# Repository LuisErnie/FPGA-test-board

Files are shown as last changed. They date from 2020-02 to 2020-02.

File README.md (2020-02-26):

# FPGA-test-board
FPGA Test Board designed for use with **DE10-NANO** by Terasic to provide external I/O devices to interface with the FPGA:
- 40 pin GPIO header split into 5 PMod ports
- 16x2 Character LCD
- 2 UART RS-485 ports
- 1 UART RS-282/USB port selected with switch
- 8 Optocoupled Outputs
- 8 ADC inputs 12-bit
- 8 DIP switch input

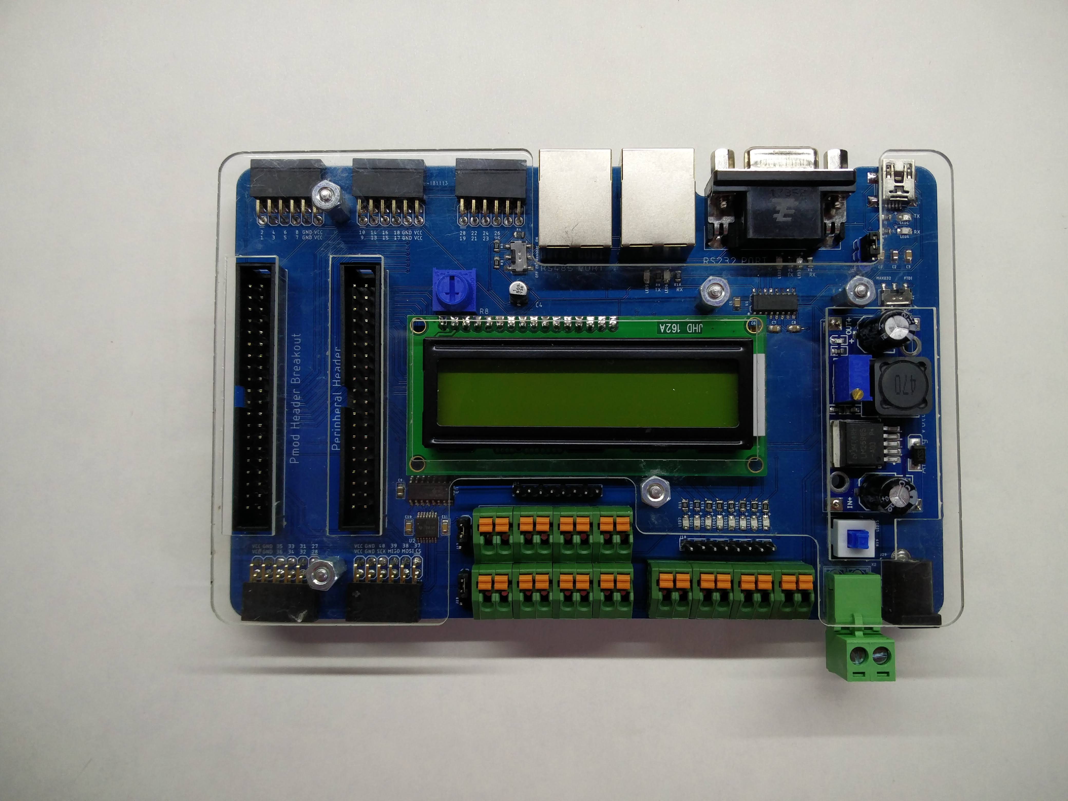
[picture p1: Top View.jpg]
Board


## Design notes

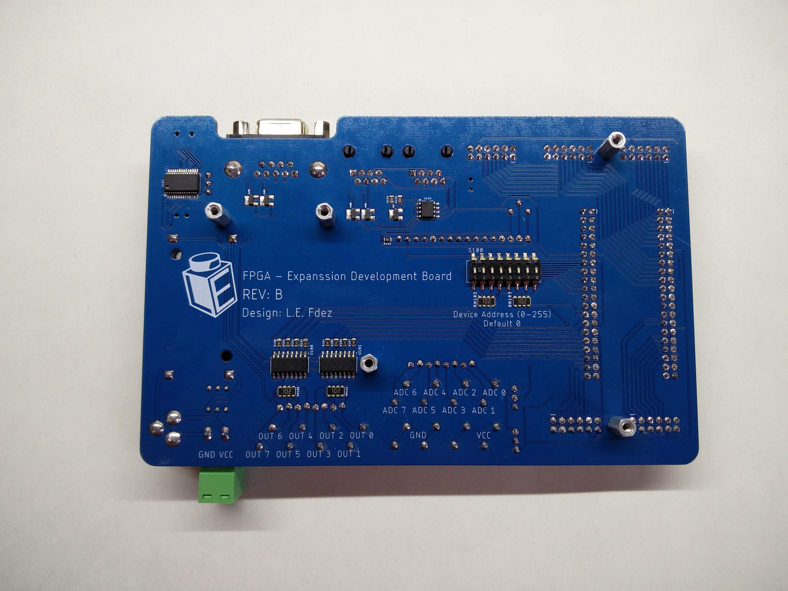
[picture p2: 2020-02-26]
Bottom View.jpg

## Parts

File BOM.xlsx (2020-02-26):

LCSC Part Number | Manufacture Part Number | Manufacturer | Package | RoHS | Order Qty. | Unit Price | Min\Mult Order Qty. | Order Price
C18148 | MAX3485ESA+T | Maxim Integrated | SOIC-8_150mil | yes | 5 | 1.632 | 1 | 8.16
C7258 | MAX3232CSE+T | Maxim Integrated | SOIC-16_150mil | yes | 5 | 1.1077 | 1 | 5.5385
C167327 | 3-1634584-2 | TE Connectivity | Connector | - | 5 | 1.3428 | 1 | 6.714
C116302 | 3386P-1-103TLF | BOURNS | 3386P | yes | 5 | 1.2498 | 1 | 6.249
C107402 | D-G080508G1-KS2 | Wuxi ARK Tech Elec | 0805 | - | 60 | 0.0203 | 20 | 1.218
C108412 | D-B080508B1-KS2 | Wuxi ARK Tech Elec | 0805 | - | 60 | 0.022 | 20 | 1.32
C91144 | U-M-M5SS-W-2 | Rectangular Connectors - Contacts | SMD | - | 5 | 0.115 | 5 | 0.575
C16338 | 2N7002LT1G | ON Semicon | SOT-23(SOT-23-3) | yes | 30 | 0.0592 | 10 | 1.776
C29926 | 0805B104J500NT | Guangdong Fenghua Advanced Tech | 0805 | yes | 20 | 0.0258 | 20 | 0.516
C60708 | TXB0104PWR | Texas Instruments | TSSOP-14 | yes | 5 | 0.7644 | 1 | 3.822
C144126 | AF0805JR-07100RL | YAGEO | 0805 | yes | 100 | 0.0104 | 50 | 1.04
C100046 | RC0805JR-071KL | YAGEO | 0805 | - | 50 | 0.0027 | 50 | 0.135
C138260 | AC0805JR-0710KL | YAGEO | 0805 | yes | 50 | 0.0131 | 50 | 0.655
C39060 | 0805F106M250NT | Guangdong Fenghua Advanced Tech | 0805 | yes | 10 | 0.0609 | 10 | 0.609
C35795 | 0805F105M500NT | Guangdong Fenghua Advanced Tech | 0805 | yes | 20 | 0.0254 | 20 | 0.508
C37818 | 0805B475K250NT | Guangdong Fenghua Advanced Tech | 0805 | yes | 10 | 0.0657 | 10 | 0.657
C178506 | EEE1HA010SR | PANASONIC | SMD,4x5.4mm | yes | 5 | 0.0639 | 5 | 0.3195
C229170 | AC0805JR-07270RL | YAGEO | 0805 | yes | 50 | 0.0047 | 50 | 0.235
C8690 | FT232RL-REEL | Future Designs | SSOP-28_208mil | yes | 5 | 3.5565 | 1 | 17.7825
C89710 | EMR-08-V | Diptronics | SMD | - | 5 | 0.4701 | 1 | 2.3505
C239357 | A2541HWR-2x6P | Changjiang Connectors | Through Hole,P=2.54mm | yes | 30 | 0.2114 | 1 | 6.342
C173392 | 41-F01-250-4 | HIWA | P=3.5mm | - | 20 | 0.1471 | 1 | 2.942
C183518 | 5EHDR-02P | Dinkle | Through Hole,P=5mm | - | 5 | 0.1387 | 1 | 0.6935
C183512 | 5ESDV-02P | Dinkle | Plug,P=5mm | - | 5 | 0.296 | 1 | 1.48
C136744 | DC-005-20A | Rectangular Connectors - Contacts | 14.0*9.0mm | yes | 5 | 0.0947 | 5 | 0.4735
C124009 | K8-8081D-L1 | Rectangular Connectors - Contacts | Self-locking Button Switch | - | 5 | 0.1184 | 1 | 0.592
C118300 | TCMT4600 | Vishay Intertech | SO-16 | yes | 10 | 1.0299 | 1 | 10.299
C132439 | - | Shenzhen Cankemeng | DIP P=2.54mm | yes | 10 | 0.2029 | 1 | 2.029
C149873 | CRA064RJ1KE04 | Ever Ohms Tech | 1206_x4 | yes | 20 | 0.0602 | 10 | 1.204
C86576 | DS1128-04-S8B8P-X | CONNFLY Elec | Plugin | yes | 10 | 0.3907 | 1 | 3.907

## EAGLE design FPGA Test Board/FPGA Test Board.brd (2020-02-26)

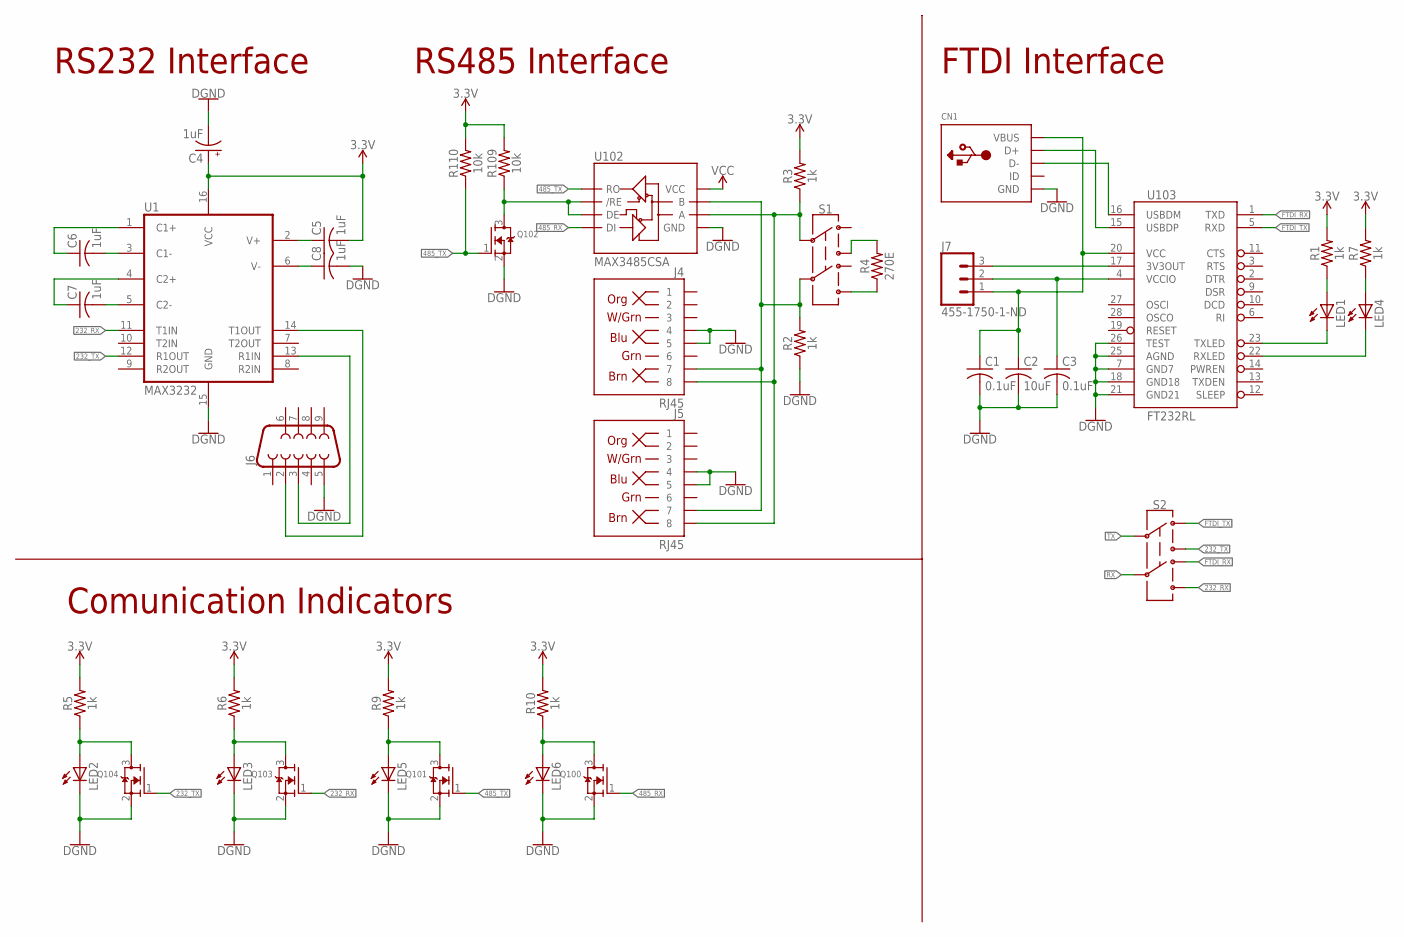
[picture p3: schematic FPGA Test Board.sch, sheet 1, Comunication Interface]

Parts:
C1, C3: 0.1uF; C0805
C2: 10uF; C0805
C4: 1uF; PANASONIC_B
C5, C6, C7, C8: 1uF; C0805
CN1: USBMINIB; USB-MINIB
J4, J5: RJ45; RJ45-8
J6: DB9FEMALE; DB9
J7: 455-1750-1-ND; 1X03
LED1, LED2, LED3, LED4, LED5, LED6: LEDCHIP-LED0805; CHIP-LED0805
Q100, Q101, Q102, Q103, Q104: MOSFET-NWAVE; SOT23-W
R1, R2, R3, R5, R6, R7, R9, R10: 1k; 0805
R4: 270E; 0805
R109, R110: 10k; 0805
S1, S2: SWITCH-DPDT-SMD-AYZ0202; SWITCH_DPDT_SMD_AYZ0202
U1: MAX3232; SO16
U102: MAX3485CSA; SO08
U103: FT232RL; SSOP28DB

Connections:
3.3V: C4.+, C5.2, R1.2, R3.2, R5.2, R6.2, R7.2, R9.2, R10.2, R109.2, R110.2, U1.16 (VCC); also elsewhere on the board
5V: U102.8 (VCC); also elsewhere on the board
232_RX: Q103.1 (G), S2.6, U1.11 (T1IN); also elsewhere on the board
232_TX: Q104.1 (G), S2.3, U1.12 (R1OUT); also elsewhere on the board
485_RX: Q100.1 (G), U102.4 (DI); also elsewhere on the board
485_TX: Q101.1 (G), Q102.1 (G), R110.1, U102.1 (RO); also elsewhere on the board
FTDI_RX: S2.4, U103.1 (TXD)
FTDI_TX: S2.1, U103.5 (RXD)
GND: C1.2, C2.2, C3.2, C4.-, C8.2, CN1.GND, J4.4, J4.5, J5.4, J5.5, J6.5, LED2.C, LED3.C, LED5.C, LED6.C, Q100.2 (S), Q101.2 (S), Q102.2 (S), Q103.2 (S), Q104.2 (S), R2.1, U1.15 (GND), U102.5 (GND), U103.7 (GND7), U103.18 (GND18), U103.21 (GND21), U103.25 (AGND), U103.26 (TEST); also elsewhere on the board
unnamed: C6.2, U1.3 (C1-)
unnamed: C5.1, U1.2 (V+)
unnamed: C6.1, U1.1 (C1+)
unnamed: C7.1, U1.4 (C2+)
unnamed: C7.2, U1.5 (C2-)
unnamed: C8.1, U1.6 (V-)
unnamed: J4.8, J5.8, R3.1, S1.2, U102.6 (A)
unnamed: LED3.A, Q103.3 (D), R6.1
unnamed: J6.2, U1.14 (T1OUT)
unnamed: J6.3, U1.13 (R1IN)
unnamed: LED5.A, Q101.3 (D), R9.1
unnamed: LED2.A, Q104.3 (D), R5.1
unnamed: LED6.A, Q100.3 (D), R10.1
unnamed: J4.7, J5.7, R2.2, S1.5, U102.7 (B)
unnamed: R4.1, S1.6
unnamed: Q102.3 (D), R109.1, U102.2 (/RE), U102.3 (DE)
unnamed: R4.2, S1.3
unnamed: C1.1, C2.1, CN1.VBUS, J7.1, U103.20 (VCC)
unnamed: LED1.A, R1.1
unnamed: LED1.C, U103.23 (TXLED)
unnamed: LED4.A, R7.1
unnamed: LED4.C, U103.22 (RXLED)
unnamed: CN1.D-, U103.16 (USBDM)
unnamed: CN1.D+, U103.15 (USBDP)
unnamed: J7.3, U103.17 (3V3OUT)
unnamed: C3.1, J7.2, U103.4 (VCCIO)
RX: S2.5
TX: S2.2

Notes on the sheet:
RS232 Interface
RS485 Interface
Comunication Indicators
FTDI Interface

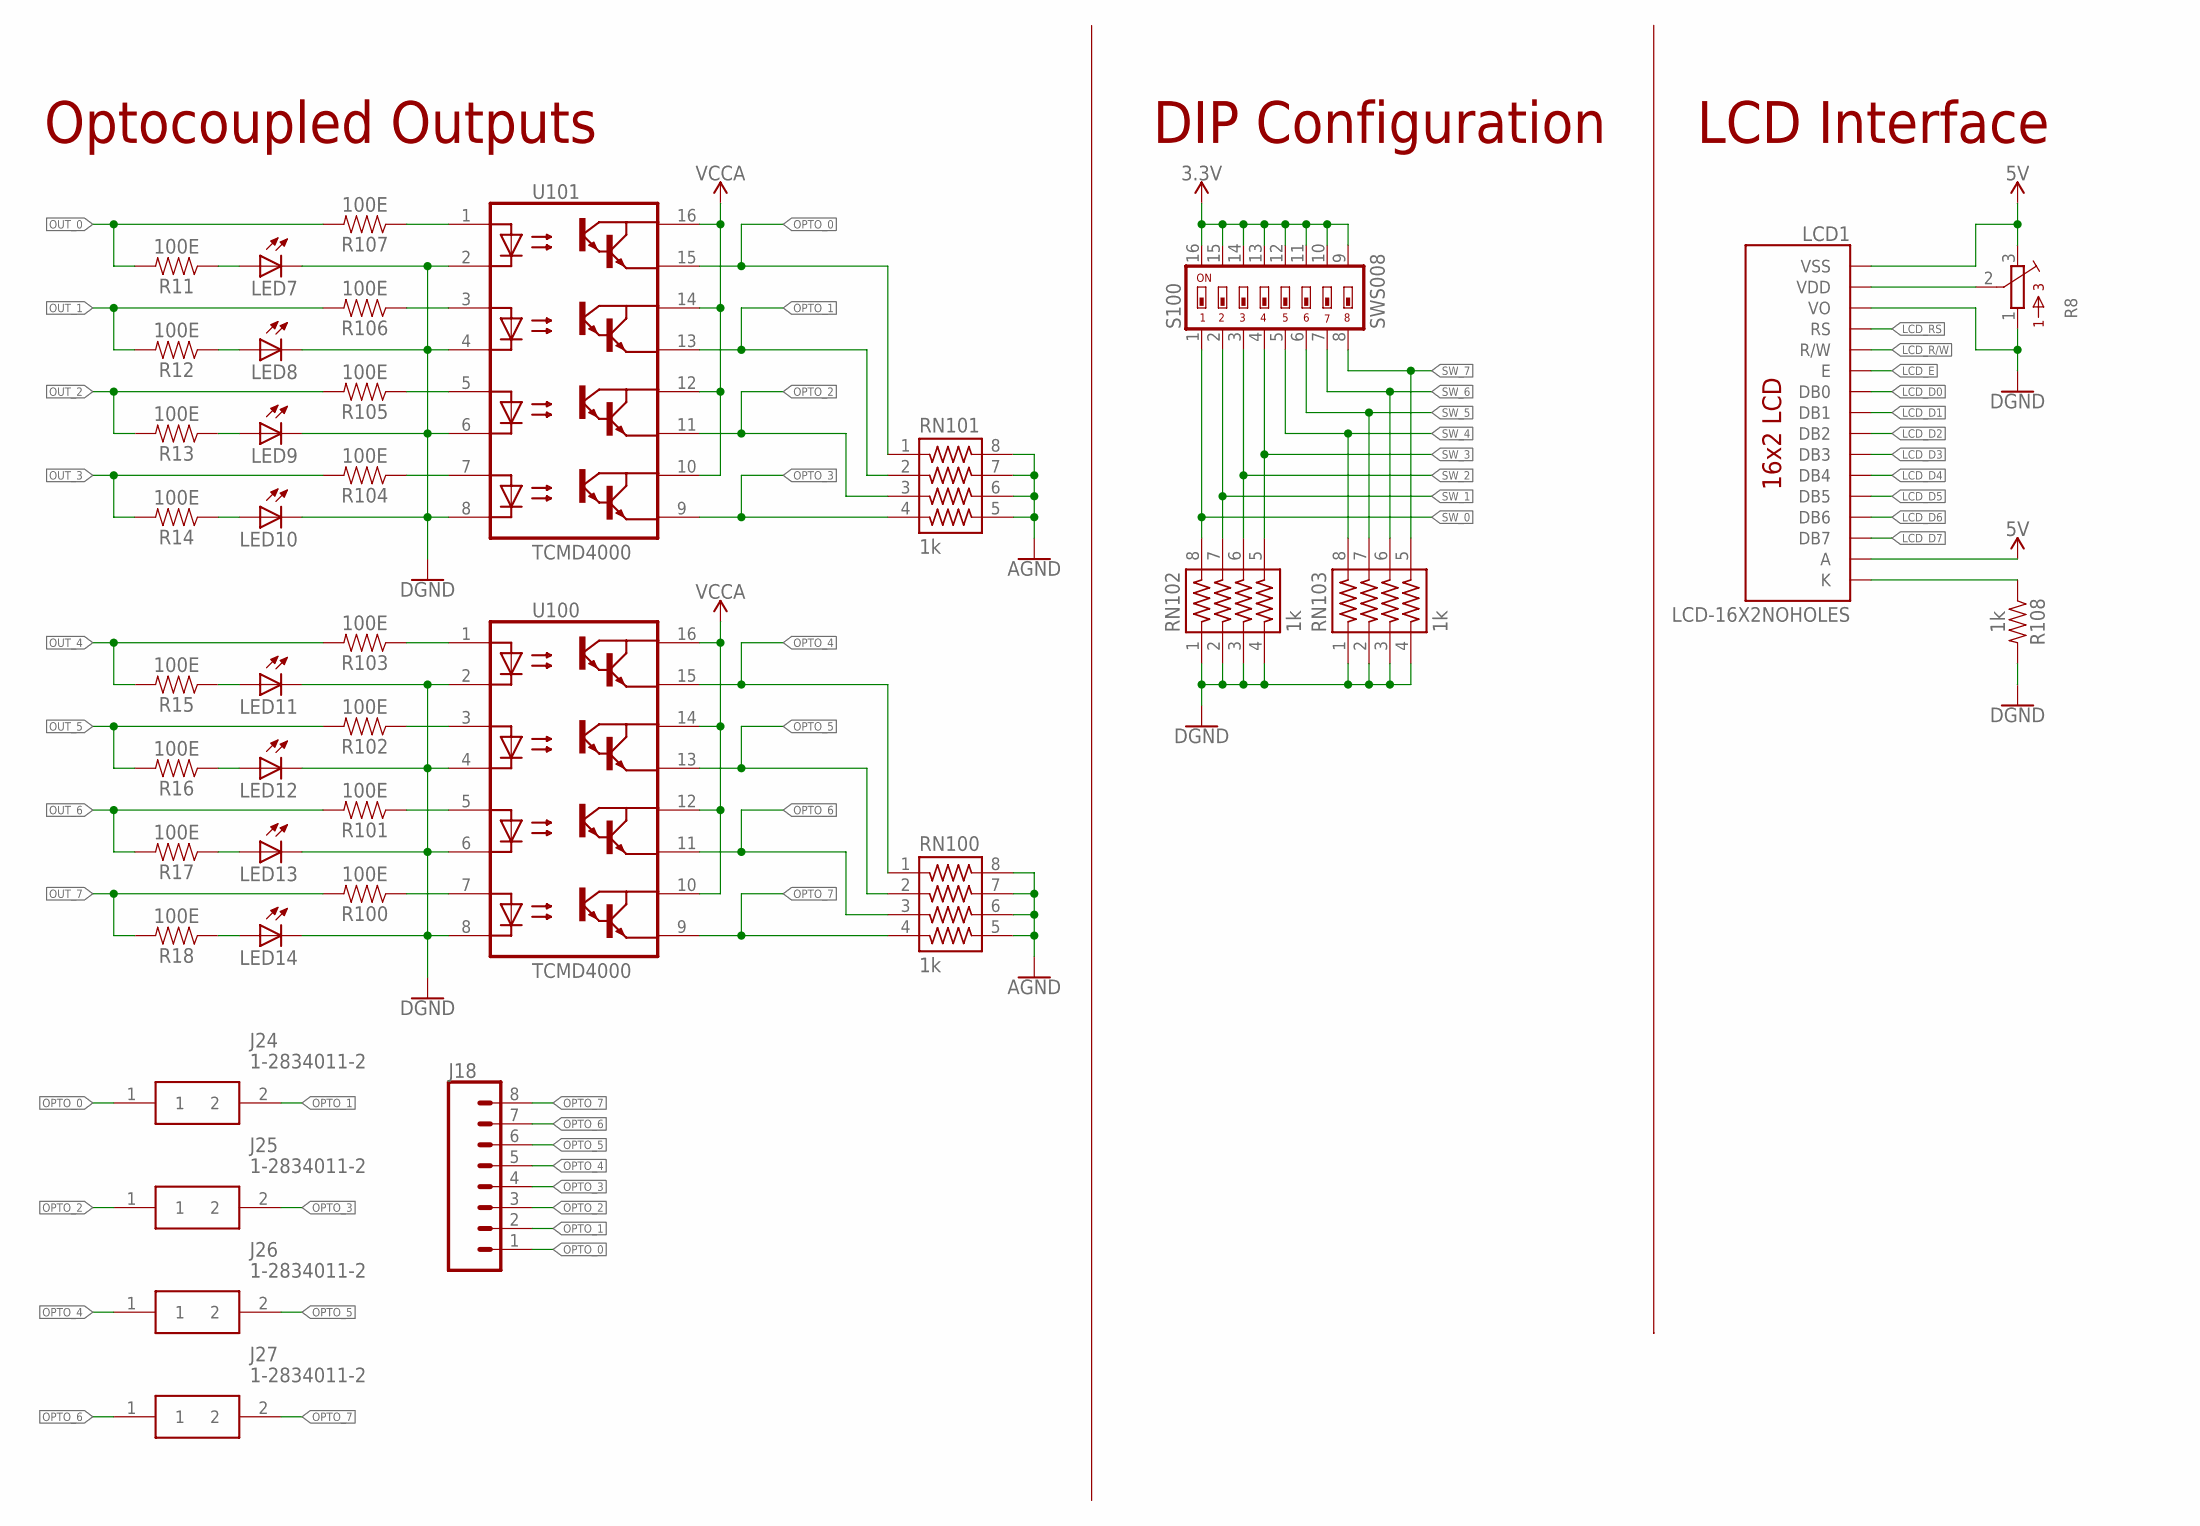
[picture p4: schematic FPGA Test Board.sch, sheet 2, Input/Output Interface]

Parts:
J18: CONN_08FEMALE_LOCK; 1X08_FEMALE_LOCK
J24, J25, J26, J27: 1-2834011-2; 128340112
LCD1: LCD-16X2NOHOLES; LCD-16X2_NOHOLESNOSILK
LED7, LED8, LED9, LED10, LED11, LED12, LED13, LED14: LEDCHIP-LED0805; CHIP-LED0805
R8: 3386-P; 3386P
R11, R12, R13, R14, R15, R16, R17, R18, R100, R101, R102, R103, R104, R105, R106, R107: 100E; 0805
R108: 1k; 0805
RN100, RN101, RN102, RN103: 1k; 743-8NS
S100: SWS008; SMS-008
U100, U101: TCMD4000; SOIC127P686X201-16N

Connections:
3.3V: S100.9, S100.10, S100.11, S100.12, S100.13, S100.14, S100.15, S100.16; also elsewhere on the board
5V: LCD1.1 (VSS), LCD1.15 (A), R8.3; also elsewhere on the board
AGND: RN100.5, RN100.6, RN100.7, RN100.8, RN101.5, RN101.6, RN101.7, RN101.8; also elsewhere on the board
GND: LCD1.3 (VO), LED7.C, LED8.C, LED9.C, LED10.C, LED11.C, LED12.C, LED13.C, LED14.C, R8.1, R108.2, RN102.1, RN102.2, RN102.3, RN102.4, RN103.1, RN103.2, RN103.3, RN103.4, U100.2 (C1), U100.4 (C2), U100.6 (C3), U100.8 (C4), U101.2 (C1), U101.4 (C2), U101.6 (C3), U101.8 (C4); also elsewhere on the board
LCD_D0: LCD1.7 (DB0); also elsewhere on the board
LCD_D1: LCD1.8 (DB1); also elsewhere on the board
LCD_D2: LCD1.9 (DB2); also elsewhere on the board
LCD_D3: LCD1.10 (DB3); also elsewhere on the board
LCD_D4: LCD1.11 (DB4); also elsewhere on the board
LCD_D5: LCD1.12 (DB5); also elsewhere on the board
LCD_D6: LCD1.13 (DB6); also elsewhere on the board
LCD_D7: LCD1.14 (DB7); also elsewhere on the board
LCD_E: LCD1.6 (E); also elsewhere on the board
LCD_R/W: LCD1.5 (R/W); also elsewhere on the board
LCD_RS: LCD1.4 (RS); also elsewhere on the board
unnamed: LCD1.2 (VDD), R8.2
unnamed: LCD1.16 (K), R108.1
unnamed: R107.1, U101.1 (A1)
unnamed: R106.1, U101.3 (A2)
unnamed: R105.1, U101.5 (A3)
unnamed: R104.1, U101.7 (A4)
unnamed: LED10.A, R14.1
unnamed: LED9.A, R13.1
unnamed: LED8.A, R12.1
unnamed: LED7.A, R11.1
unnamed: R103.1, U100.1 (A1)
unnamed: R102.1, U100.3 (A2)
unnamed: R101.1, U100.5 (A3)
unnamed: R100.1, U100.7 (A4)
unnamed: LED14.A, R18.1
unnamed: LED13.A, R17.1
unnamed: LED12.A, R16.1
unnamed: LED11.A, R15.1
OPTO_0: J18.1, J24.1, RN101.1, U101.15 (E1)
OPTO_1: J18.2, J24.2, RN101.2, U101.13 (E2)
OPTO_2: J18.3, J25.1, RN101.3, U101.11 (E3)
OPTO_3: J18.4, J25.2, RN101.4, U101.9 (E4)
OPTO_4: J18.5, J26.1, RN100.1, U100.15 (E1)
OPTO_5: J18.6, J26.2, RN100.2, U100.13 (E2)
OPTO_6: J18.7, J27.1, RN100.3, U100.11 (E3)
OPTO_7: J18.8, J27.2, RN100.4, U100.9 (E4)
OUT_0: R11.2, R107.2; also elsewhere on the board
OUT_1: R12.2, R106.2; also elsewhere on the board
OUT_2: R13.2, R105.2; also elsewhere on the board
OUT_3: R14.2, R104.2; also elsewhere on the board
OUT_4: R15.2, R103.2; also elsewhere on the board
OUT_5: R16.2, R102.2; also elsewhere on the board
OUT_6: R17.2, R101.2; also elsewhere on the board
OUT_7: R18.2, R100.2; also elsewhere on the board
SW_0: RN102.8, S100.1; also elsewhere on the board
SW_1: RN102.7, S100.2; also elsewhere on the board
SW_2: RN102.6, S100.3; also elsewhere on the board
SW_3: RN102.5, S100.4; also elsewhere on the board
SW_4: RN103.8, S100.5; also elsewhere on the board
SW_5: RN103.7, S100.6; also elsewhere on the board
SW_6: RN103.6, S100.7; also elsewhere on the board
SW_7: RN103.5, S100.8; also elsewhere on the board
VCCA: U100.10 (CO4), U100.12 (CO3), U100.14 (CO2), U100.16 (CO1), U101.10 (CO4), U101.12 (CO3), U101.14 (CO2), U101.16 (CO1); also elsewhere on the board

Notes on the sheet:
Optocoupled Outputs
DIP Configuration
LCD Interface

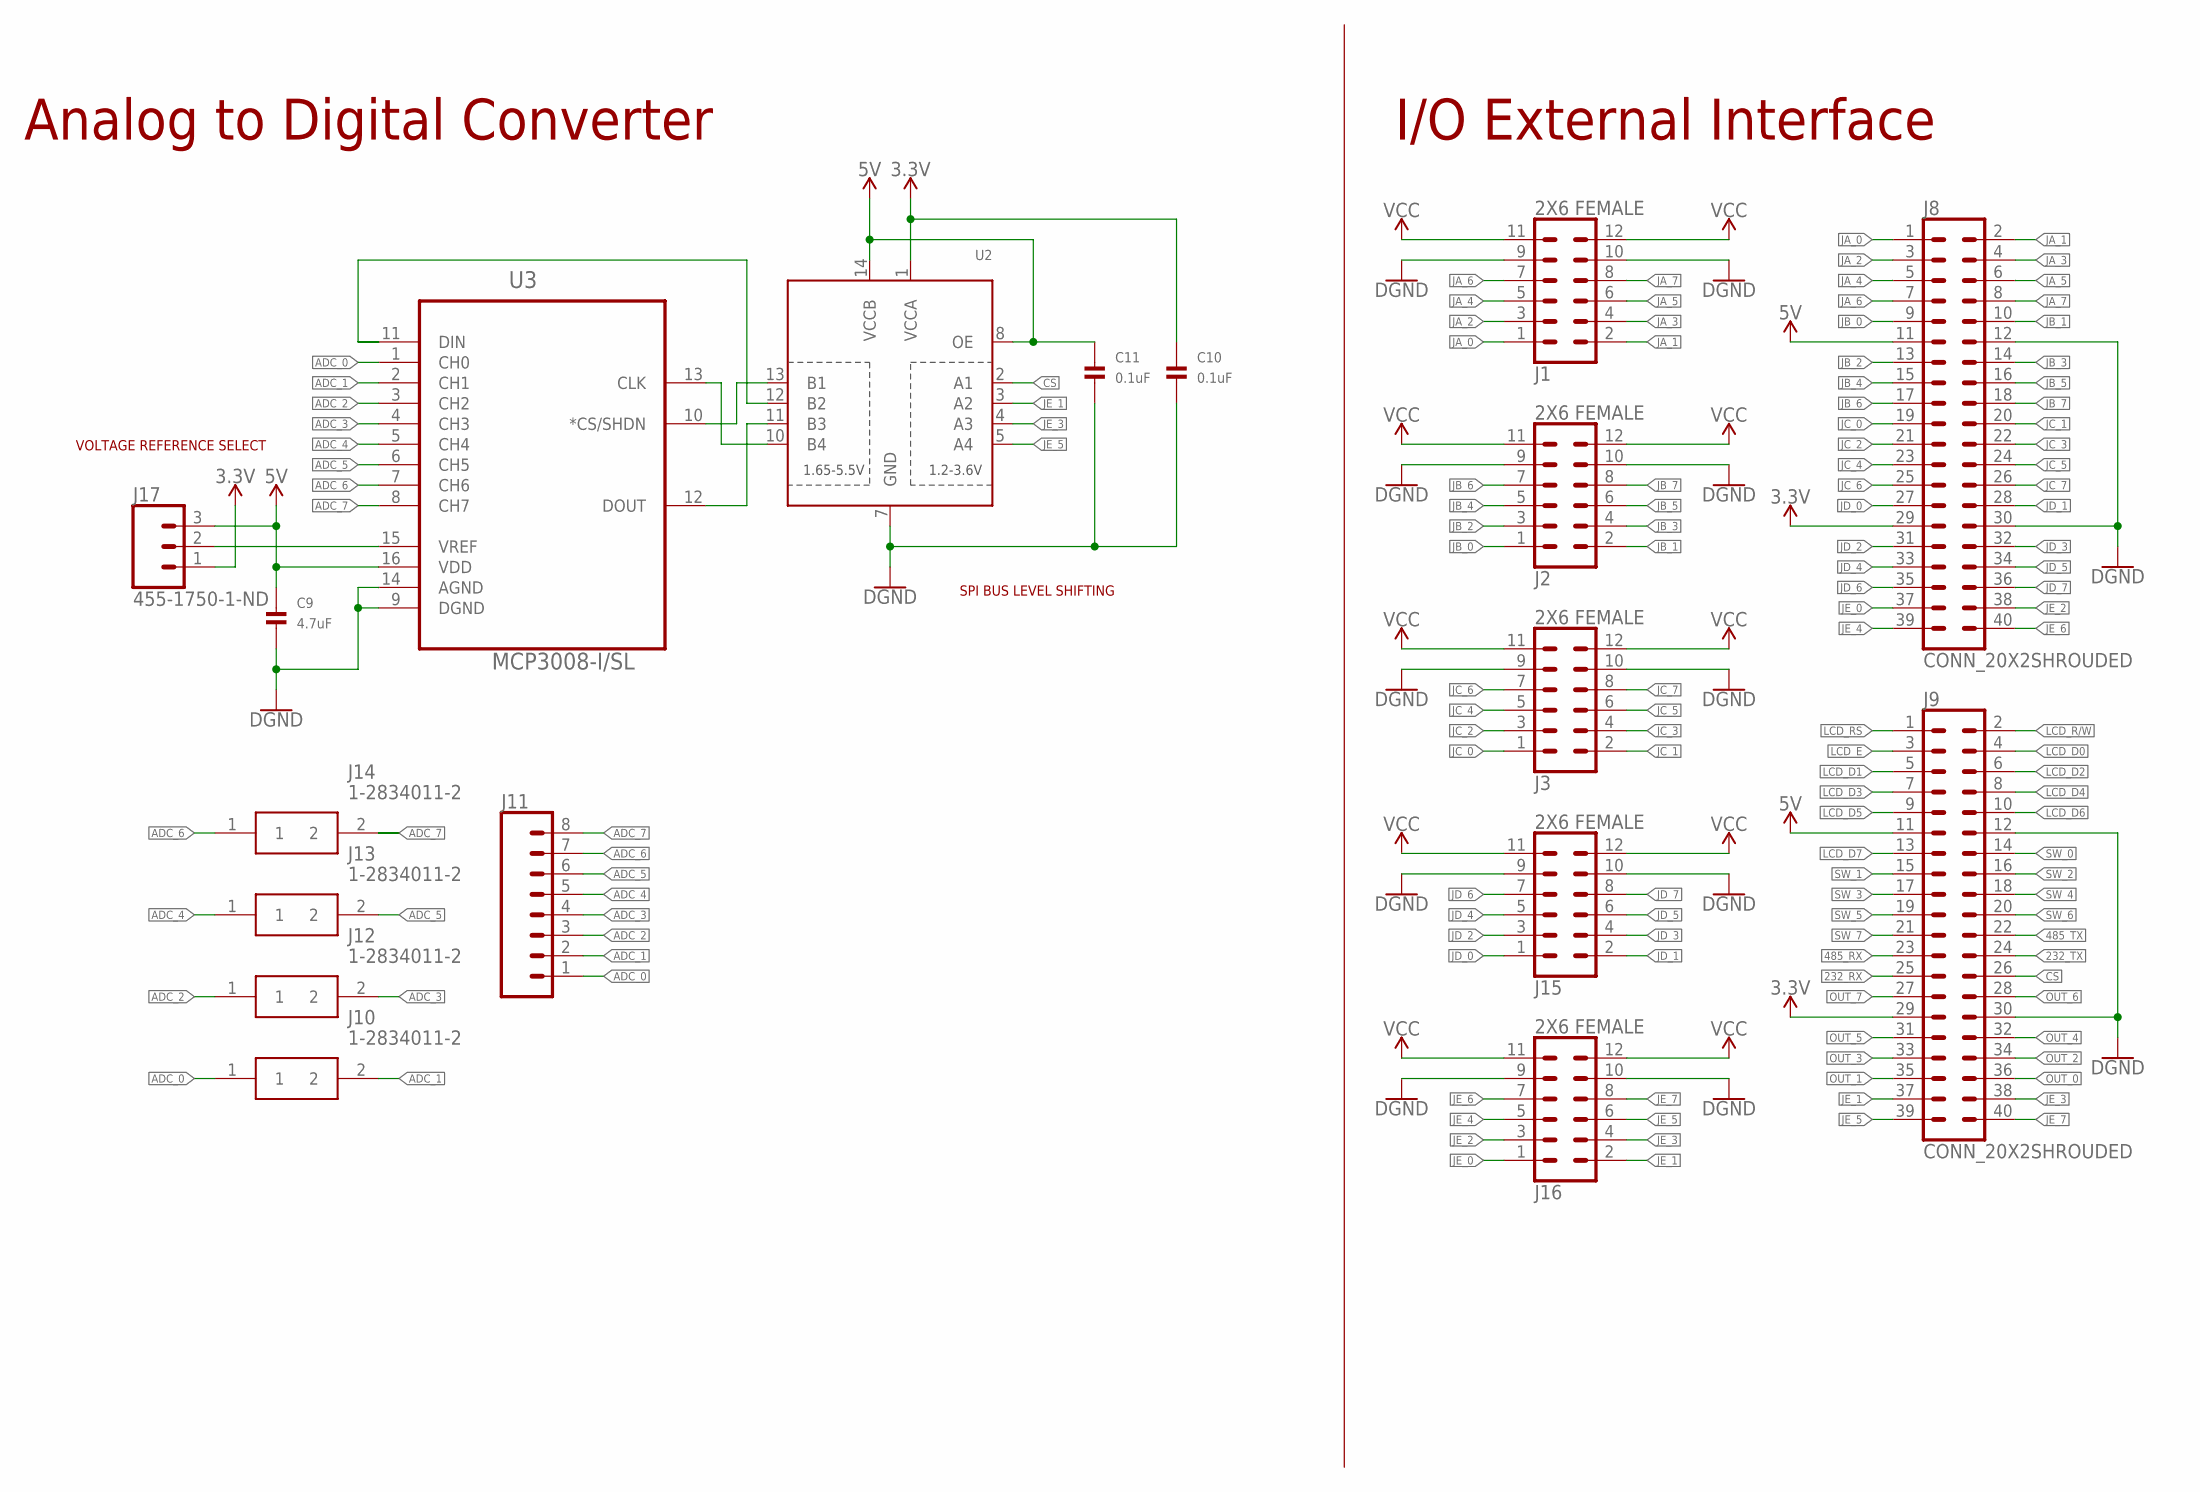
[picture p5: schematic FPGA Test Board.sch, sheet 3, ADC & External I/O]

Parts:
C9: 4.7uF; 0805_NOTHERMALS
C10, C11: 0.1uF; 0805_NOTHERMALS
J1, J2, J3, J15, J16: 2X6 FEMALE; 2X6
J8, J9: CONN_20X2SHROUDED; 2X20_SHROUDED
J10, J12, J13, J14: 1-2834011-2; 128340112
J11: CONN_08FEMALE_LOCK; 1X08_FEMALE_LOCK
J17: 455-1750-1-ND; 1X03
U2: TXB0104PWR; TSSOP14
U3: MCP3008-I/SL; SOIC127P600X175-16N

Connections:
3.3V: C10.1, J8.29, J9.29, J17.1, U2.1 (VCCA); also elsewhere on the board
5V: C9.1, C11.1, J8.11, J9.11, J17.3, U2.8 (OE), U2.14 (VCCB), U3.16 (VDD); also elsewhere on the board
232_RX: J9.25; also elsewhere on the board
232_TX: J9.24; also elsewhere on the board
485_RX: J9.23; also elsewhere on the board
485_TX: J9.22; also elsewhere on the board
ADC_0: J10.1, J11.1, U3.1 (CH0)
ADC_1: J10.2, J11.2, U3.2 (CH1)
ADC_2: J11.3, J12.1, U3.3 (CH2)
ADC_3: J11.4, J12.2, U3.4 (CH3)
ADC_4: J11.5, J13.1, U3.5 (CH4)
ADC_5: J11.6, J13.2, U3.6 (CH5)
ADC_6: J11.7, J14.1, U3.7 (CH6)
ADC_7: J11.8, J14.2, U3.8 (CH7)
CS: J9.26, U2.2 (A1)
GND: C9.2, C10.2, C11.2, J1.9, J1.10, J2.9, J2.10, J3.9, J3.10, J8.12, J8.30, J9.12, J9.30, J15.9, J15.10, J16.9, J16.10, U2.7 (GND), U3.9 (DGND), U3.14 (AGND); also elsewhere on the board
JA_0: J1.1, J8.1
JA_1: J1.2, J8.2
JA_2: J1.3, J8.3
JA_3: J1.4, J8.4
JA_4: J1.5, J8.5
JA_5: J1.6, J8.6
JA_6: J1.7, J8.7
JA_7: J1.8, J8.8
JB_0: J2.1, J8.9
JB_1: J2.2, J8.10
JB_2: J2.3, J8.13
JB_3: J2.4, J8.14
JB_4: J2.5, J8.15
JB_5: J2.6, J8.16
JB_6: J2.7, J8.17
JB_7: J2.8, J8.18
JC_0: J3.1, J8.19
JC_1: J3.2, J8.20
JC_2: J3.3, J8.21
JC_3: J3.4, J8.22
JC_4: J3.5, J8.23
JC_5: J3.6, J8.24
JC_6: J3.7, J8.25
JC_7: J3.8, J8.26
JD_0: J8.27, J15.1
JD_1: J8.28, J15.2
JD_2: J8.31, J15.3
JD_3: J8.32, J15.4
JD_4: J8.33, J15.5
JD_5: J8.34, J15.6
JD_6: J8.35, J15.7
JD_7: J8.36, J15.8
JE_0: J8.37, J16.1
JE_1: J9.37, J16.2, U2.3 (A2)
JE_2: J8.38, J16.3
JE_3: J9.38, J16.4, U2.4 (A3)
JE_4: J8.39, J16.5
JE_5: J9.39, J16.6, U2.5 (A4)
JE_6: J8.40, J16.7
JE_7: J9.40, J16.8
LCD_D0: J9.4; also elsewhere on the board
LCD_D1: J9.5; also elsewhere on the board
LCD_D2: J9.6; also elsewhere on the board
LCD_D3: J9.7; also elsewhere on the board
LCD_D4: J9.8; also elsewhere on the board
LCD_D5: J9.9; also elsewhere on the board
LCD_D6: J9.10; also elsewhere on the board
LCD_D7: J9.13; also elsewhere on the board
LCD_E: J9.3; also elsewhere on the board
LCD_R/W: J9.2; also elsewhere on the board
LCD_RS: J9.1; also elsewhere on the board
unnamed: U2.13 (B1), U3.10 (*CS/SHDN)
unnamed: U2.10 (B4), U3.13 (CLK)
unnamed: U2.11 (B3), U3.12 (DOUT)
unnamed: U2.12 (B2), U3.11 (DIN)
unnamed: J17.2, U3.15 (VREF)
OUT_0: J9.36; also elsewhere on the board
OUT_1: J9.35; also elsewhere on the board
OUT_2: J9.34; also elsewhere on the board
OUT_3: J9.33; also elsewhere on the board
OUT_4: J9.32; also elsewhere on the board
OUT_5: J9.31; also elsewhere on the board
OUT_6: J9.28; also elsewhere on the board
OUT_7: J9.27; also elsewhere on the board
SW_0: J9.14; also elsewhere on the board
SW_1: J9.15; also elsewhere on the board
SW_2: J9.16; also elsewhere on the board
SW_3: J9.17; also elsewhere on the board
SW_4: J9.18; also elsewhere on the board
SW_5: J9.19; also elsewhere on the board
SW_6: J9.20; also elsewhere on the board
SW_7: J9.21; also elsewhere on the board
VCC: J1.11, J1.12, J2.11, J2.12, J3.11, J3.12, J15.11, J15.12, J16.11, J16.12; also elsewhere on the board

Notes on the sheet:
VOLTAGE REFERENCE SELECT
SPI BUS LEVEL SHIFTING
Analog to Digital Converter
I/O External Interface

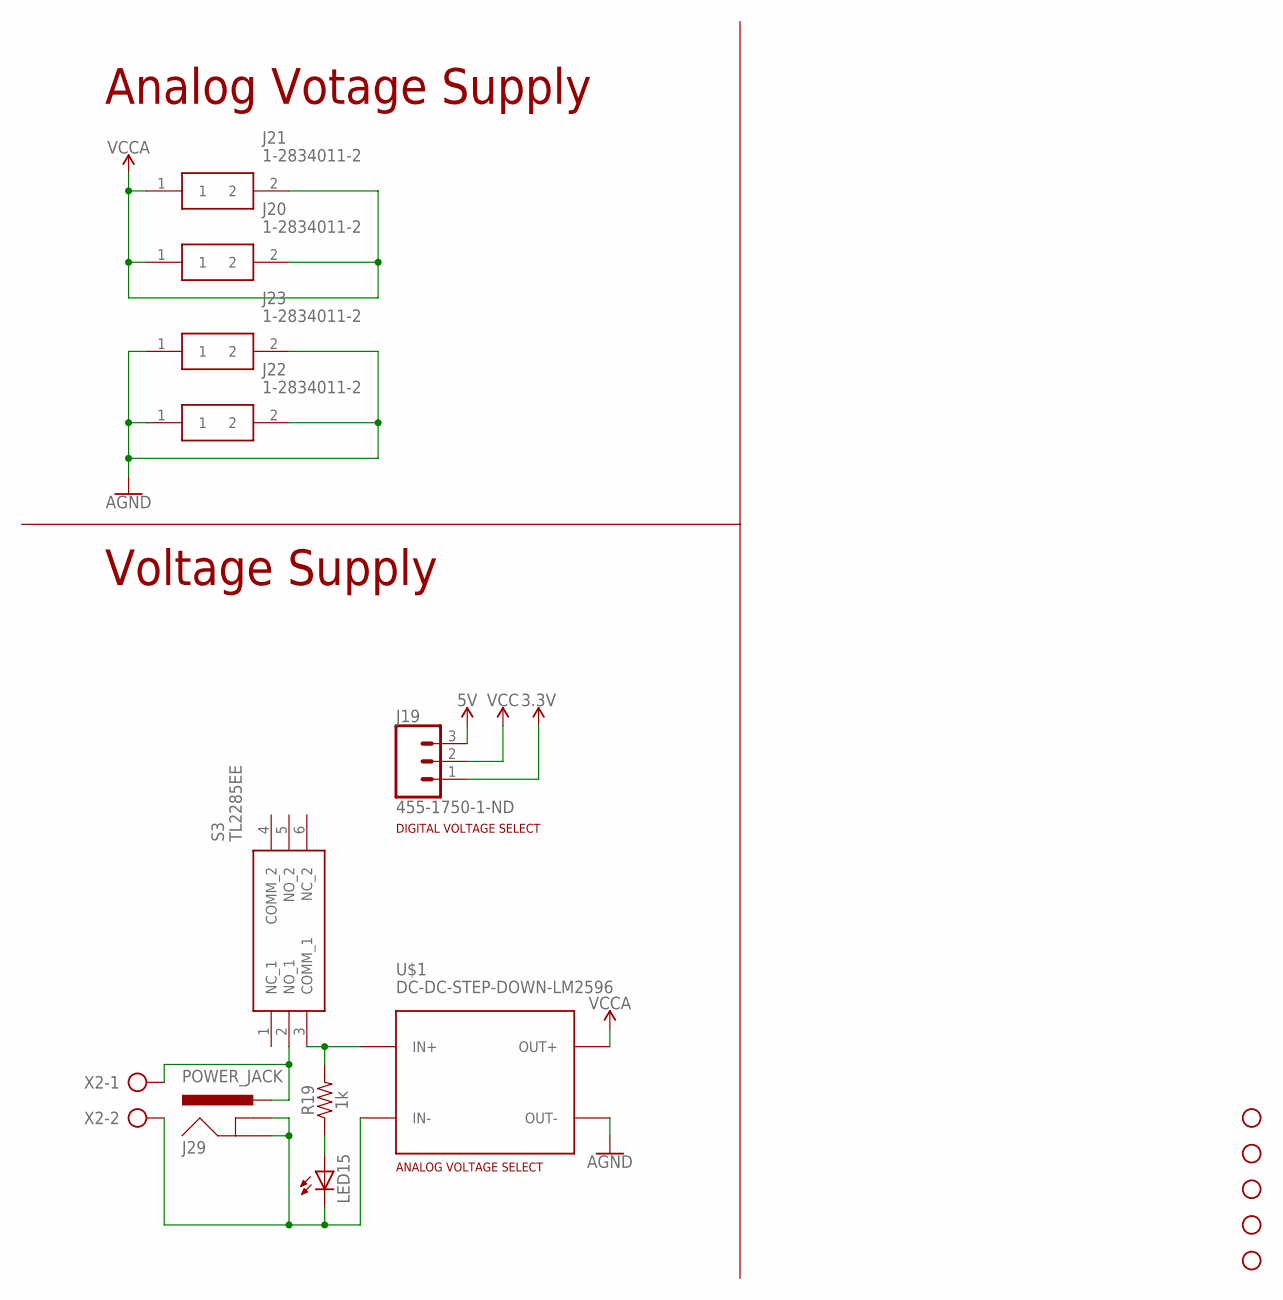
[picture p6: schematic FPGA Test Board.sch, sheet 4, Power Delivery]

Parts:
H1, H5, H6, H7, H8: STAND-OFF
J19: 455-1750-1-ND; 1X03
J20, J21, J22, J23: 1-2834011-2; 128340112
J29: POWER_JACK; POWER_JACK_PTH
LED15: LEDCHIP-LED0805; CHIP-LED0805
R19: 1k; 0805
S3: TL2285EE
U$1: DC-DC-STEP-DOWN-LM2596
X2: AK500/2-H

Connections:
3.3V: J19.1; also elsewhere on the board
5V: J19.3; also elsewhere on the board
AGND: J22.1, J22.2, J23.1, J23.2, U$1.OUT-; also elsewhere on the board
unnamed: R19.2, S3.3 (COMM_1), U$1.IN+
unnamed: LED15.A, R19.1
unnamed: J29.PWR, S3.2 (NO_1), X2.1
unnamed: J29.GND, J29.GNDBREAK, LED15.C, U$1.IN-, X2.2
VCC: J19.2; also elsewhere on the board
VCCA: J20.1, J20.2, J21.1, J21.2, U$1.OUT+; also elsewhere on the board

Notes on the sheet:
DIGITAL VOLTAGE SELECT
ANALOG VOLTAGE SELECT
Analog Votage Supply
Voltage Supply

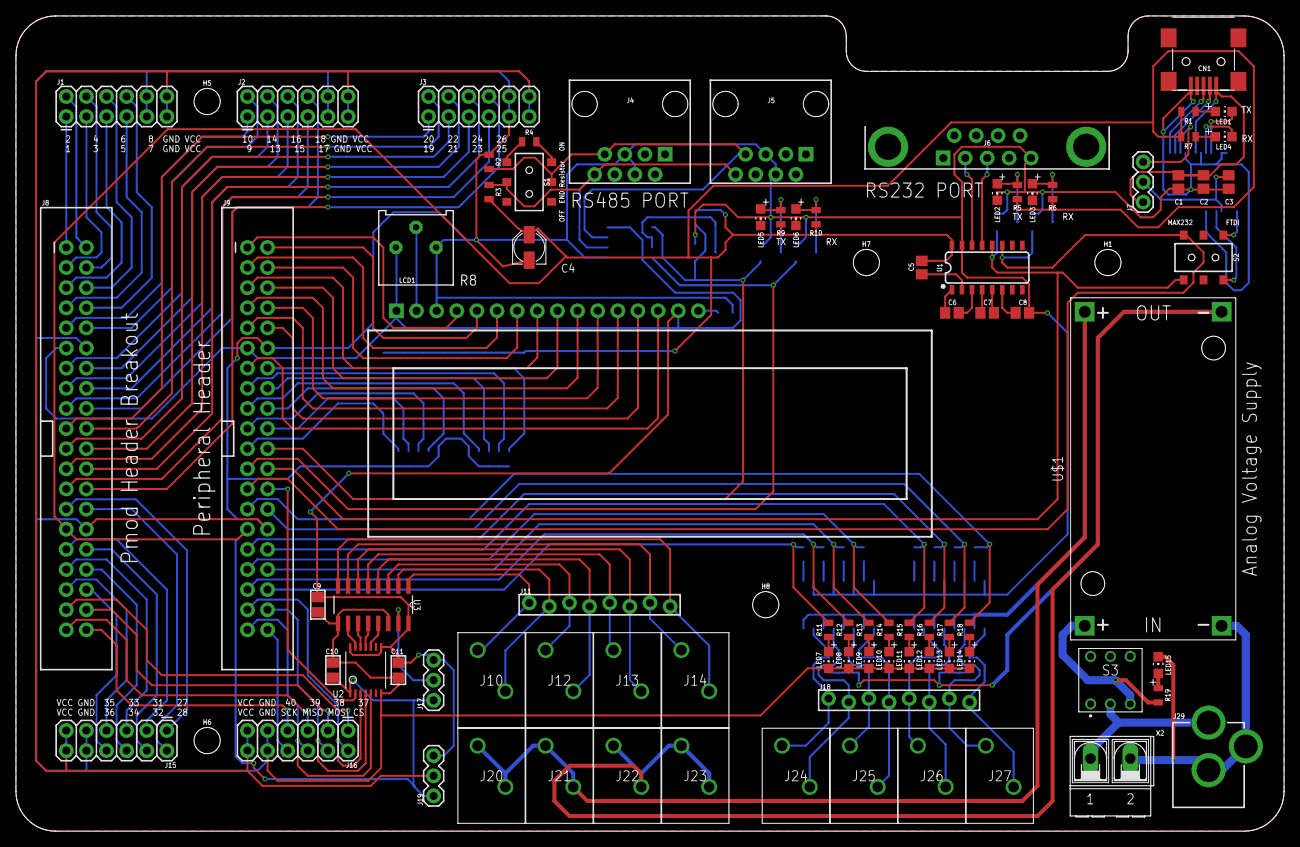
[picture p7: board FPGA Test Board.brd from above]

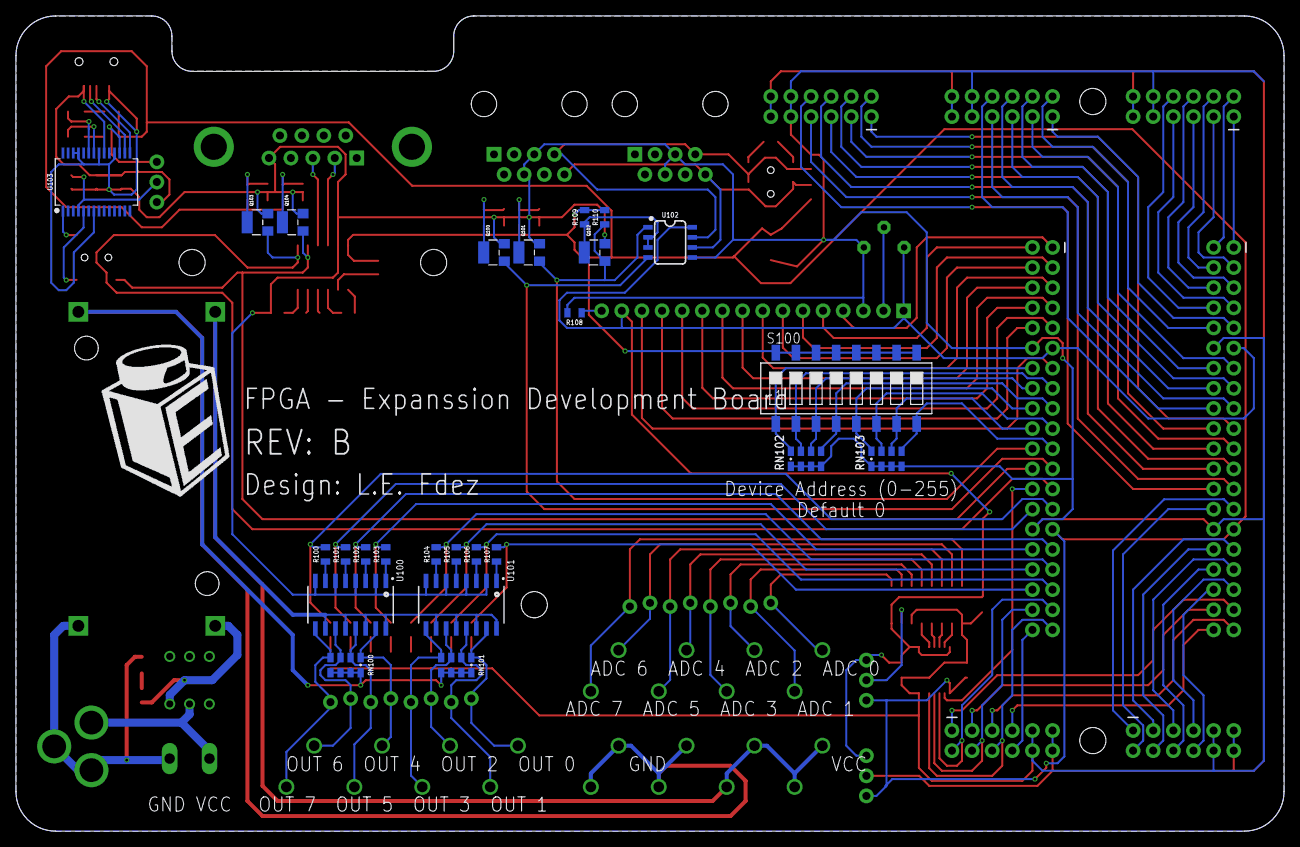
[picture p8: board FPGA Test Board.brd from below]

Board: 2 copper layers, 160.0 x 102.9 mm, 113 parts (25 on the bottom side), 149 nets.

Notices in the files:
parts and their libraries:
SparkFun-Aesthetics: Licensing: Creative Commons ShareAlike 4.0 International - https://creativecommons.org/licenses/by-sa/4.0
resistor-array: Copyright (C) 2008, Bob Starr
